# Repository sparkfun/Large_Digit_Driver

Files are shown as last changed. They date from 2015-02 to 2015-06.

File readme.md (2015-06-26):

SparkFun Large Digit Driver
============================
SparkFun Large Digit Driver

[*SparkFun Large Digit Driver (WIG-13279)*](https://www.sparkfun.com/products/13279)

The SparkFun Large Digit Driver is a chainable controller backpack that can be soldered directly to the back of our large 6.5" 7-segment displays.

Repository Contents
-------------------

* **/Firmware** - Example code 
* **/Hardware** - Eagle design files (.brd, .sch)
* **/Production** - Production panel files (.brd)

Documentation
--------------
* **[Hookup Guide](https://learn.sparkfun.com/tutorials/large-digit-driver-hookup-guide)** - Basic hookup guide for the Large Digit Driver.
* **[SparkFun Fritzing repo](https://github.com/sparkfun/Fritzing_Parts)** - Fritzing diagrams for SparkFun products.
* **[SparkFun 3D Model repo](https://github.com/sparkfun/3D_Models)** - 3D models of SparkFun products. 

License Information
-------------------

This product is _**open source**_! 

Please review the LICENSE.md file for license information. 

If you have any questions or concerns on licensing, please contact techsupport@sparkfun.com.

Distributed as-is; no warranty is given.

- Your friends at SparkFun.

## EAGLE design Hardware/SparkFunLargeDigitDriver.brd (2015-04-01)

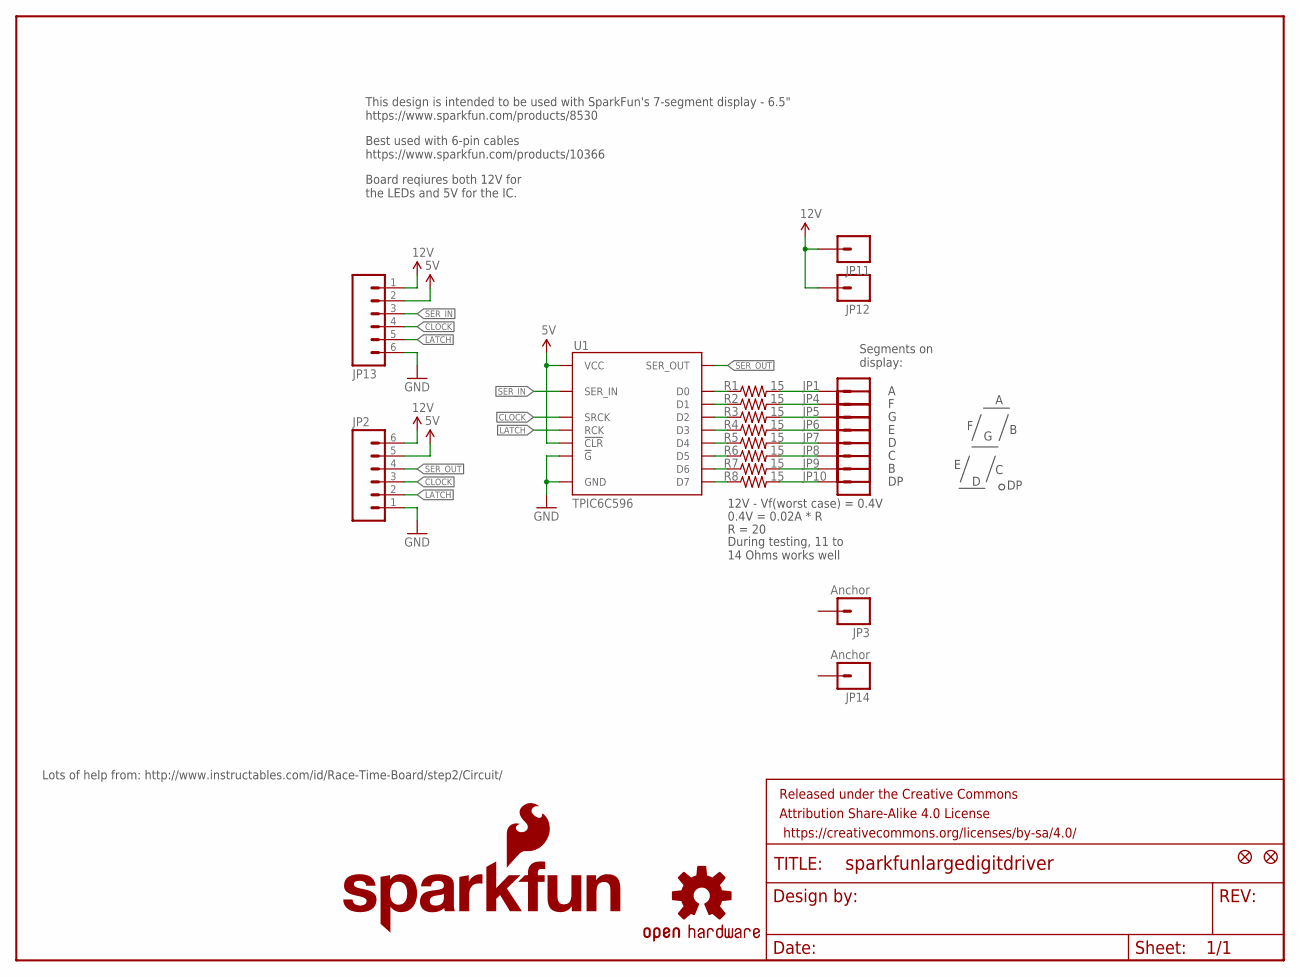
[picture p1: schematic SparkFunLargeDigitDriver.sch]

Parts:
FID1, FID2: FIDUCIAL1X2; FIDUCIAL-1X2
FRAME1: FRAME-LETTER; CREATIVE_COMMONS
JP1, JP4, JP5, JP6, JP7, JP8, JP9, JP10, JP11, JP12: M01PTH_LONGPAD; 1X01_LONGPAD
JP2, JP13: M06SMD; 1X06-SMD
JP3, JP14: Anchor; 1X01_LONGPAD
LOGO1: SFE_LOGO_NAME_FLAME.1_INCH; SFE_LOGO_NAME_FLAME_.1
LOGO2: OSHW-LOGOS; OSHW-LOGO-S
R1, R2, R3, R4, R5, R6, R7, R8: 15; 0603-RES
U1: TPIC6C596; SO016

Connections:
5V: JP2.5, JP13.2, U1.1 (VCC), U1.7 (!CLR)
12V: JP2.6, JP11.1, JP12.1, JP13.1
CLOCK: JP2.3, JP13.4, U1.15 (SRCK)
D0: R1.1, U1.3 (D0)
D1: R2.1, U1.4 (D1)
D2: R3.1, U1.5 (D2)
D3: R4.1, U1.6 (D3)
D4: R5.1, U1.11 (D4)
D5: R6.1, U1.12 (D5)
D6: R7.1, U1.13 (D6)
D7: R8.1, U1.14 (D7)
GND: JP2.1, JP13.6, U1.8 (!G), U1.16 (GND)
LATCH: JP2.2, JP13.5, U1.10 (RCK)
S0: JP1.1, R1.2
S1: JP4.1, R2.2
S2: JP5.1, R3.2
S3: JP6.1, R4.2
S4: JP7.1, R5.2
S5: JP8.1, R6.2
S6: JP9.1, R7.2
S7: JP10.1, R8.2
SER_IN: JP13.3, U1.2 (SER_IN)
SER_OUT: JP2.4, U1.9 (SER_OUT)

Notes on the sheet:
Lots of help from: http://www.instructables.com/id/Race-Time-Board/step2/Circuit/
Segments on display:
12V - Vf(worst case) = 0.4V
0.4V = 0.02A * R
R = 20
This design is intended to be used with SparkFun's 7-segment display - 6.5" https://www.sparkfun.com/products/8530
During testing, 11 to 14 Ohms works well
Best used with 6-pin cables https://www.sparkfun.com/products/10366
Board reqiures both 12V for the LEDs and 5V for the IC.

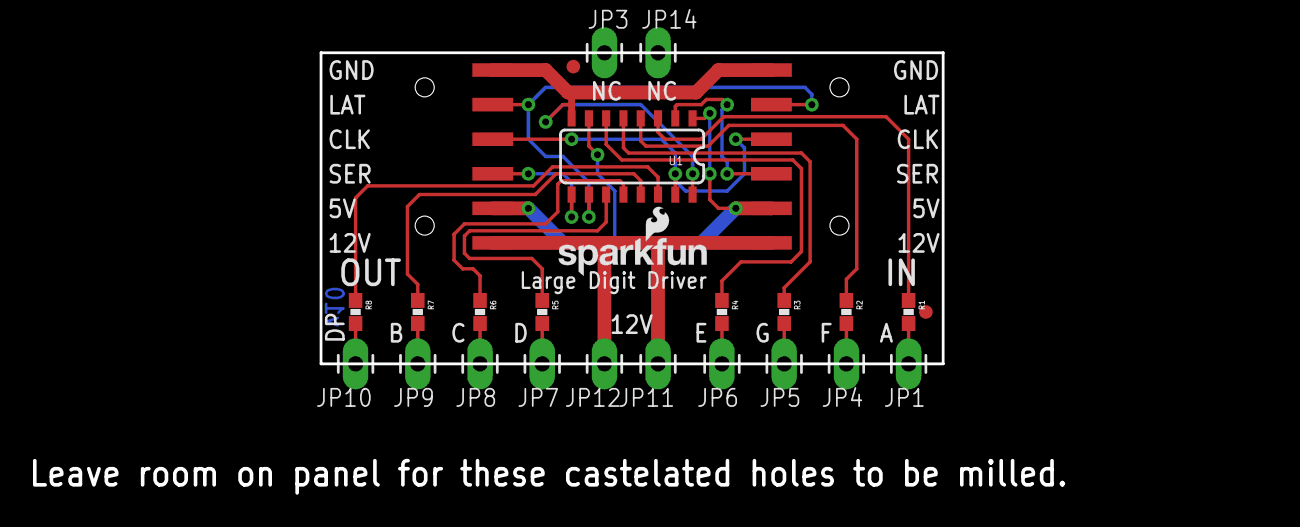
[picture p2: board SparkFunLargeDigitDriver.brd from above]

Board: 2 copper layers, 45.7 x 22.9 mm, 28 parts (1 on the bottom side), 23 nets.

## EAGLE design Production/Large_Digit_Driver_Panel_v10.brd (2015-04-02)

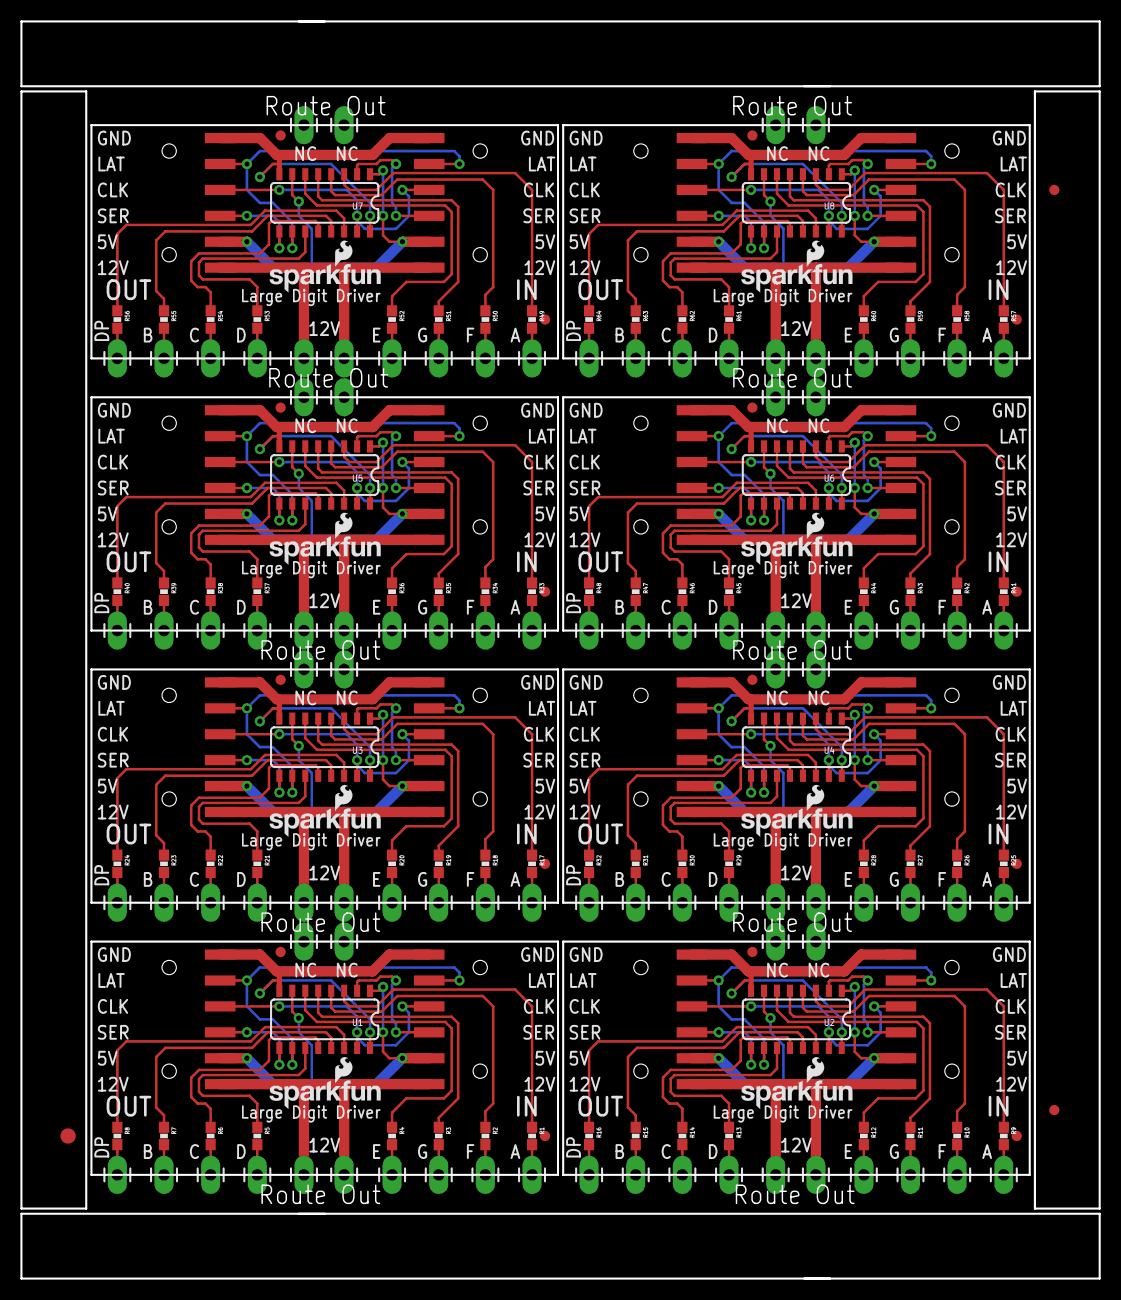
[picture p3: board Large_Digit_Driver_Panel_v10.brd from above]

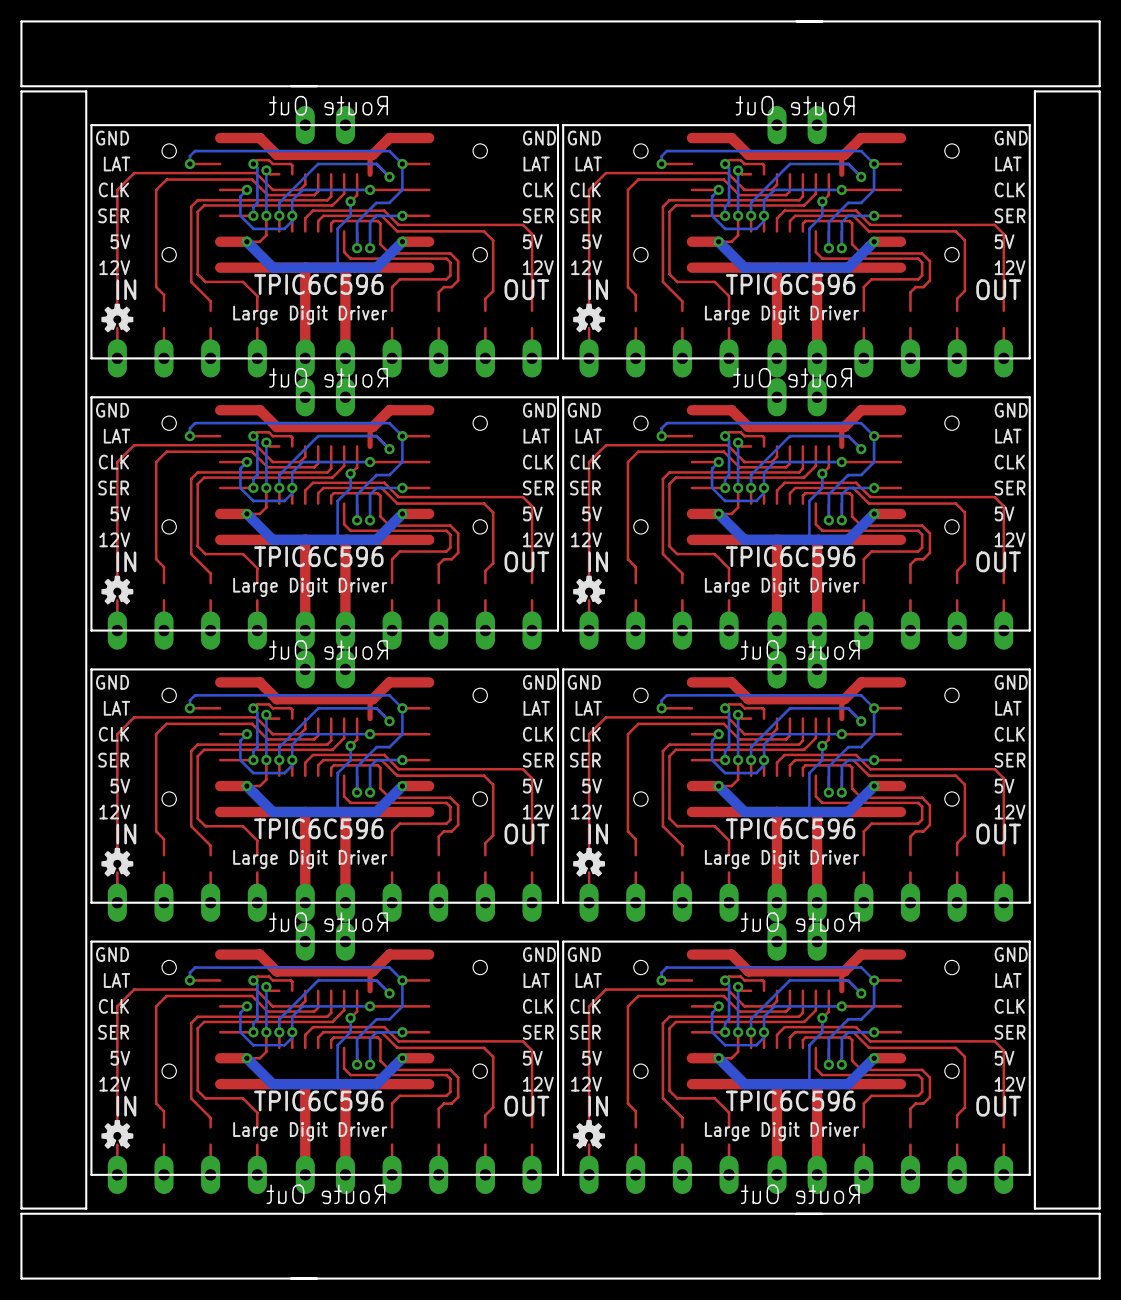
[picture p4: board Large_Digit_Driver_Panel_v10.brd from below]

Board: 2 copper layers, 105.7 x 123.2 mm, 219 parts (8 on the bottom side), 184 nets.

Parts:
E$1: FIDUCIAL-1.5X3
E$4, E$5: FIDUCIAL-1X2
FID1, FID2, FID3, FID4, FID5, FID6, FID7, FID8, FID9, FID10, FID11, FID12, FID13, FID14, FID15, FID16: FIDUCIAL1X2; FIDUCIAL-1X2
JP1, JP4, JP5, JP6, JP7, JP8, JP9, JP10, JP11, JP12, JP16, JP17, JP18, JP19, JP20, JP21, JP22, JP23, JP24, JP25, JP30, JP31, JP32, JP33, JP34, JP35, JP36, JP37, JP38, JP39, JP44, JP45, JP46, JP47, JP48, JP49, JP50, JP51, JP52, JP53, JP58, JP59, JP60, JP61, JP62, JP63, JP64, JP65, JP66, JP67, JP72, JP73, JP74, JP75, JP76, JP77, JP78, JP79, JP80, JP81, JP86, JP87, JP88, JP89, JP90, JP91, JP92, JP93, JP94, JP95, JP100, JP101, JP102, JP103, JP104, JP105, JP106, JP107, JP108, JP109: 1X01_LONGPAD
JP2, JP13, JP15, JP26, JP29, JP40, JP43, JP54, JP57, JP68, JP71, JP82, JP85, JP96, JP99, JP110: 1X06-SMD
JP3, JP14, JP27, JP28, JP41, JP42, JP55, JP56, JP69, JP70, JP83, JP84, JP97, JP98, JP111, JP112: Anchor; 1X01_LONGPAD
LOGO1, LOGO4, LOGO6, LOGO8, LOGO10, LOGO12, LOGO14, LOGO16: SFE_LOGO_NAME_FLAME.1_INCH; SFE_LOGO_NAME_FLAME_.1
LOGO2, LOGO3, LOGO5, LOGO7, LOGO9, LOGO11, LOGO13, LOGO15: OSHW-LOGOS; OSHW-LOGO-S
R1, R2, R3, R4, R5, R6, R7, R8, R9, R10, R11, R12, R13, R14, R15, R16, R17, R18, R19, R20, R21, R22, R23, R24, R25, R26, R27, R28, R29, R30, R31, R32, R33, R34, R35, R36, R37, R38, R39, R40, R41, R42, R43, R44, R45, R46, R47, R48, R49, R50, R51, R52, R53, R54, R55, R56, R57, R58, R59, R60, R61, R62, R63, R64: 15; 0603-RES
U1, U2, U3, U4, U5, U6, U7, U8: TPIC6C596; SO016

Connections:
5V: JP2.5, JP13.2, U1.1, U1.7
5V1: JP15.5, JP26.2, U2.1, U2.7
5V2: JP29.5, JP40.2, U3.1, U3.7
5V3: JP43.5, JP54.2, U4.1, U4.7
5V4: JP57.5, JP68.2, U5.1, U5.7
5V5: JP71.5, JP82.2, U6.1, U6.7
5V6: JP85.5, JP96.2, U7.1, U7.7
5V7: JP99.5, JP110.2, U8.1, U8.7
12V: JP2.6, JP11.1, JP12.1, JP13.1
12V1: JP15.6, JP24.1, JP25.1, JP26.1
12V2: JP29.6, JP38.1, JP39.1, JP40.1
12V3: JP43.6, JP52.1, JP53.1, JP54.1
12V4: JP57.6, JP66.1, JP67.1, JP68.1
12V5: JP71.6, JP80.1, JP81.1, JP82.1
12V6: JP85.6, JP94.1, JP95.1, JP96.1
12V7: JP99.6, JP108.1, JP109.1, JP110.1
CLOCK: JP2.3, JP13.4, U1.15
CLOCK1: JP15.3, JP26.4, U2.15
CLOCK2: JP29.3, JP40.4, U3.15
CLOCK3: JP43.3, JP54.4, U4.15
CLOCK4: JP57.3, JP68.4, U5.15
CLOCK5: JP71.3, JP82.4, U6.15
CLOCK6: JP85.3, JP96.4, U7.15
CLOCK7: JP99.3, JP110.4, U8.15
D0: R1.1, U1.3
D1: R2.1, U1.4
D2: R3.1, U1.5
D3: R4.1, U1.6
D4: R5.1, U1.11
D5: R6.1, U1.12
D6: R7.1, U1.13
D7: R8.1, U1.14
D8: R9.1, U2.3
D9: R10.1, U2.4
D10: R11.1, U2.5
D11: R12.1, U2.6
D12: R13.1, U2.11
D13: R14.1, U2.12
D14: R15.1, U2.13
D15: R16.1, U2.14
D16: R17.1, U3.3
D17: R18.1, U3.4
D18: R19.1, U3.5
D19: R20.1, U3.6
D20: R21.1, U3.11
D21: R22.1, U3.12
D22: R23.1, U3.13
D23: R24.1, U3.14
D24: R25.1, U4.3
D25: R26.1, U4.4
D26: R27.1, U4.5
D27: R28.1, U4.6
D28: R29.1, U4.11
D29: R30.1, U4.12
D30: R31.1, U4.13
D31: R32.1, U4.14
D32: R33.1, U5.3
D33: R34.1, U5.4
D34: R35.1, U5.5
D35: R36.1, U5.6
D36: R37.1, U5.11
D37: R38.1, U5.12
D38: R39.1, U5.13
D39: R40.1, U5.14
D40: R41.1, U6.3
D41: R42.1, U6.4
D42: R43.1, U6.5
D43: R44.1, U6.6
D44: R45.1, U6.11
D45: R46.1, U6.12
D46: R47.1, U6.13
D47: R48.1, U6.14
D48: R49.1, U7.3
D49: R50.1, U7.4
D50: R51.1, U7.5
D51: R52.1, U7.6
D52: R53.1, U7.11
D53: R54.1, U7.12
D54: R55.1, U7.13
D55: R56.1, U7.14
D56: R57.1, U8.3
D57: R58.1, U8.4
D58: R59.1, U8.5
D59: R60.1, U8.6
D60: R61.1, U8.11
D61: R62.1, U8.12
D62: R63.1, U8.13
D63: R64.1, U8.14
GND: JP2.1, JP13.6, U1.8, U1.16
GND1: JP15.1, JP26.6, U2.8, U2.16
GND2: JP29.1, JP40.6, U3.8, U3.16
GND3: JP43.1, JP54.6, U4.8, U4.16
GND4: JP57.1, JP68.6, U5.8, U5.16
GND5: JP71.1, JP82.6, U6.8, U6.16
GND6: JP85.1, JP96.6, U7.8, U7.16
GND7: JP99.1, JP110.6, U8.8, U8.16
LATCH: JP2.2, JP13.5, U1.10
LATCH1: JP15.2, JP26.5, U2.10
LATCH2: JP29.2, JP40.5, U3.10
LATCH3: JP43.2, JP54.5, U4.10
LATCH4: JP57.2, JP68.5, U5.10
LATCH5: JP71.2, JP82.5, U6.10
LATCH6: JP85.2, JP96.5, U7.10
LATCH7: JP99.2, JP110.5, U8.10
S0: JP1.1, R1.2
S1: JP4.1, R2.2
S2: JP5.1, R3.2
S3: JP6.1, R4.2
S4: JP7.1, R5.2
S5: JP8.1, R6.2
S6: JP9.1, R7.2
S7: JP10.1, R8.2
S8: JP16.1, R9.2
S9: JP17.1, R10.2
S10: JP18.1, R11.2
S11: JP19.1, R12.2
S12: JP20.1, R13.2
S13: JP21.1, R14.2
S14: JP22.1, R15.2
S15: JP23.1, R16.2
S16: JP30.1, R17.2
S17: JP31.1, R18.2
S18: JP32.1, R19.2
S19: JP33.1, R20.2
S20: JP34.1, R21.2
S21: JP35.1, R22.2
S22: JP36.1, R23.2
S23: JP37.1, R24.2
S24: JP44.1, R25.2
S25: JP45.1, R26.2
S26: JP46.1, R27.2
S27: JP47.1, R28.2
S28: JP48.1, R29.2
S29: JP49.1, R30.2
S30: JP50.1, R31.2
S31: JP51.1, R32.2
S32: JP58.1, R33.2
S33: JP59.1, R34.2
S34: JP60.1, R35.2
S35: JP61.1, R36.2
S36: JP62.1, R37.2
S37: JP63.1, R38.2
S38: JP64.1, R39.2
S39: JP65.1, R40.2
S40: JP72.1, R41.2
S41: JP73.1, R42.2
S42: JP74.1, R43.2
S43: JP75.1, R44.2
S44: JP76.1, R45.2
S45: JP77.1, R46.2
S46: JP78.1, R47.2
S47: JP79.1, R48.2
S48: JP86.1, R49.2
S49: JP87.1, R50.2
S50: JP88.1, R51.2
S51: JP89.1, R52.2
S52: JP90.1, R53.2
S53: JP91.1, R54.2
S54: JP92.1, R55.2
S55: JP93.1, R56.2
S56: JP100.1, R57.2
S57: JP101.1, R58.2
S58: JP102.1, R59.2
S59: JP103.1, R60.2
S60: JP104.1, R61.2
S61: JP105.1, R62.2
S62: JP106.1, R63.2
S63: JP107.1, R64.2
SER_IN: JP13.3, U1.2
SER_IN1: JP26.3, U2.2
SER_IN2: JP40.3, U3.2
SER_IN3: JP54.3, U4.2
SER_IN4: JP68.3, U5.2
SER_IN5: JP82.3, U6.2
SER_IN6: JP96.3, U7.2
SER_IN7: JP110.3, U8.2
SER_OUT: JP2.4, U1.9
SER_OUT1: JP15.4, U2.9
SER_OUT2: JP29.4, U3.9
SER_OUT3: JP43.4, U4.9
SER_OUT4: JP57.4, U5.9
SER_OUT5: JP71.4, U6.9
SER_OUT6: JP85.4, U7.9
SER_OUT7: JP99.4, U8.9

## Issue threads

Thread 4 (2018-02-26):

Display showing 88 (All leds are glowing)

afsar95, 2018-02-26:
We have developed a prototype using Large_digits with nodemcu, Everything is fine when connections made out of jumper wires but digit shows 88 when the connections made in PCB...I used 12v to 5v voltage(1amps)  regulator for powering board please help with me..Thanks in advance...

nseidle, 2018-02-26:
Perhaps you could post your code, or a schematic? Otherwise, I have really no idea.

afsar95, 2018-02-27:
#include <DHT.h>
#define DHTPIN 2    //d4
#define DHTTYPE DHT22
#define HUM_LED 14       //D5                
#define TEM_LED 12       //D6

DHT dht(DHTPIN, DHTTYPE);

byte segmentClock = 5;//D1
byte segmentLatch = 4;//D2
byte segmentData = 0;//D3
//esp8266 nodemcu
void setup() {
  Serial.begin(115200);
  pinMode(segmentClock, OUTPUT);
  pinMode(segmentData, OUTPUT);
  pinMode(segmentLatch, OUTPUT);
  pinMode(HUM_LED, OUTPUT);
  pinMode(TEM_LED, OUTPUT);
  digitalWrite(HUM_LED, LOW);
  digitalWrite(TEM_LED, LOW);
  digitalWrite(segmentClock, LOW);
  digitalWrite(segmentData, LOW);
  digitalWrite(segmentLatch, LOW);
  dht.begin();
  showNumber1(88);
  digitalWrite(HUM_LED, HIGH);
  digitalWrite(TEM_LED, HIGH);
  delay(3000);
}

void loop() {
  int Humidity = dht.readHumidity();
  Humidity = Humidity - 3;   //ADJUSTMENT
  int Temperature_Cel = dht.readTemperature();
  if (isnan(Humidity) || isnan(Temperature_Cel))
  {
    Serial.println("Failed to read from DHT sensor!");
  }
  if ((Humidity > 0 && Temperature_Cel > 0) && (Humidity < 100 && Temperature_Cel < 100)) {
    Serial.print("Humidity: ");
    Serial.print(Humidity);
    Serial.print(" %\t");
    Serial.print("Temperature: ");
    Serial.print(Temperature_Cel);
    Serial.print(" *C ");
    digitalWrite(HUM_LED, HIGH);
    digitalWrite(TEM_LED, LOW);
    showNumber(Humidity);
    delay(2000);
    digitalWrite(HUM_LED, LOW);
    digitalWrite(TEM_LED, HIGH);
    showNumber(Temperature_Cel);
    delay(2000);
  }
  else {
    Serial.println("invalid data");
  }

}
void showNumber(float value)
{
  int number = abs(value); //Remove negative signs and any decimals
  for (byte x = 0 ; x < 2 ; x++)
  {
    int remainder = number % 10;
    postNumber(remainder, false);
    number /= 10;
  }
  digitalWrite(segmentLatch, LOW);
  digitalWrite(segmentLatch, HIGH);
}
void postNumber(byte number, boolean decimal)
{
#define a  1<<0
#define b  1<<6
#define c  1<<5
#define d  1<<4
#define e  1<<3
#define f  1<<1
#define g  1<<2
#define dp 1<<7
  byte segments;
  switch (number)
  {
    case 1: segments = b | c; break;
    case 2: segments = a | b | d | e | g; break;
    case 3: segments = a | b | c | d | g; break;
    case 4: segments = f | g | b | c; break;
    case 5: segments = a | f | g | c | d; break;
    case 6: segments = a | f | g | e | c | d; break;
    case 7: segments = a | b | c; break;
    case 8: segments = a | b | c | d | e | f | g; break;
    case 9: segments = a | b | c | d | f | g; break;
    case 0: segments = a | b | c | d | e | f; break;
    case ' ': segments = 0; break;
    case 'c': segments = g | e | d; break;
    case '-': segments = g; break;
    case 't': segments = g | e | d | f; break;
    case 'u': segments = b | c | d | e | f; break;
    case 'l': segments = d | e | f; break;
    case 'h': segments = f | e | g | c; break;
    case 's': segments = a | f | g | c | d; break;
  }
  if (decimal) segments |= dp;
  for (byte x = 0 ; x < 8 ; x++)
  {
    digitalWrite(segmentClock, LOW);
    digitalWrite(segmentData, segments & 1 << (7 - x));
    digitalWrite(segmentClock, HIGH);
  }
}
void showNumber1(float value)
{
  int number = abs(value);
  for (byte x = 0 ; x < 2 ; x++)
  {
    int remainder = number % 10;
    postNumber(remainder, true);
    number /= 10;
  }
  digitalWrite(segmentLatch, LOW);
  digitalWrite(segmentLatch, HIGH);
}

nseidle, 2018-02-27:
Hi - I recommend you work on the thing that does not work: the display. To do this, remove the code for your humidity and temp sensing until you get the display working. Then add code back slowly.

It looks like you are using our example code which is a very good place to start. I'm not sure why NodeMCU doesn't work. Perhaps because it is 3.3V and the backpack is expecting 5V.

afsar95, 2018-02-27:
Thank you @nseidle
We are using 2A power supply so can you tell me what's the appropriate current rating for two digit display along with nodemcu.

nseidle, 2018-02-27:
Please read the [display datasheet](https://www.sparkfun.com/datasheets/Components/YSD-1600AR6F-89.pdf) and the [backpack schematic](https://cdn.sparkfun.com/datasheets/Widgets/Large%20Digit%20Driver.pdf). Each segment has a 15Ohm resistor in line to limit the segment current to 20mA per segment. If all 7 segments are on, this is 20*7 = 140mA per digit.

A 12V 2A supply should be more than enough!

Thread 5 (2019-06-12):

Turning Off Segments

yawuar, 2019-06-12:
Hi

So I made a little project with 4 - 7 segment Display 4" (For every display I had to use the sparkfun large digit driver ofc!) and I've use a gyroscope to hold track of the rotation, every time when it has rotated for 360 degrees it increments the counter and it shows on the display.

This project is running on a battery of 50.000mAh, a.t.m I'm trying to reduce battery (project needs to run at least a week without changing battery). So I was thinking to turn off the displays when the gyro is not rotating. I programmed it, working well but there is 1 problem. Every time I clear the segments (when the gyro is not rotating) one of my sparkfun large digit driver IC gets very **warm**. I've use the showNumber function to check if the IC still gets hot but that doesn't happen. This problem is only happening when I clear the segments >.>

This the code That I've been using:

My clearSegments function
```
void clearSegments() {
  for (byte x = 0 ; x < 4 ; x++) {
      postNumber(" ", false);
  }
  digitalWrite(segmentLatch, LOW);
  digitalWrite(segmentLatch, HIGH);
}
```

The postnumber function

```
void postNumber(byte number, boolean decimal)
{
#define a  1<<0
#define b  1<<6
#define c  1<<5
#define d  1<<4
#define e  1<<3
#define f  1<<1
#define g  1<<2
#define dp 1<<7

  byte segments;

  switch (number)
  {
    case 1: segments = g | d; break;
    case 2: segments = f | g | b | dp | c; break;
    case 3: segments = f | g | b | d | c; break;
    case 4: segments = a | b | g | d; break;
    case 5: segments = f | a | b | d | c; break;
    case 6: segments = f | a | b | d | c | dp; break;
    case 7: segments = f | g | d; break;
    case 8: segments = a | b | c | d | dp | f | g; break;
    case 9: segments = a | b | c | d | f | g; break; // a | b | c | d | f | g; break
    case 0: segments = a | g | c | d | dp | f; break;
    case ' ': segments = e; break;
  }

  // Segments not working on 0
  if (decimal) segments |= e;

  //Clock these bits out to the drivers
  for (byte x = 0 ; x < 8 ; x++)
  {
    digitalWrite(segmentClock, LOW);
    digitalWrite(segmentData, segments & 1 << (7 - x));
    digitalWrite(segmentClock, HIGH); //Data transfers to the register on the rising edge of SRCK
  }
}
```

I hope you guys have an idea what I'm doing wrong and how to solve this.
Thank you very much!

nseidle, 2019-06-12:
What type of battery? 50Ahr is a big battery.

My guess is that when you power down the display the voltage on the battery rises above the rated voltage on the driver IC.

Be sure to read the [datasheet](https://cdn.sparkfun.com/datasheets/Widgets/TPIC6C596.pdf) for the max specs. 7V on the logic (really stick to 5V).

I can't see how software would cause the ICs to overheat. It is most likely a wiring or voltage issue.

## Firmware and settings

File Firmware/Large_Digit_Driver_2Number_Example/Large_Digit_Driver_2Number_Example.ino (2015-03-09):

/*
 Controlling large 7-segment displays
 By: Nathan Seidle
 SparkFun Electronics
 Date: February 25th, 2015
 License: This code is public domain but you buy me a beer if you use this and we meet someday (Beerware license).

 This code demonstrates how to post two numbers to a 2-digit display usings two large digit driver boards.

 Here's how to hook up the Arduino pins to the Large Digit Driver IN
 
 Arduino pin 6 -> CLK (Green on the 6-pin cable)
 5 -> LAT (Blue)
 7 -> SER on the IN side (Yellow)
 5V -> 5V (Orange)
 Power Arduino with 12V and connect to Vin -> 12V (Red)
 GND -> GND (Black)

 There are two connectors on the Large Digit Driver. 'IN' is the input side that should be connected to
 your microcontroller (the Arduino). 'OUT' is the output side that should be connected to the 'IN' of addtional
 digits.
 
 Each display will use about 150mA with all segments and decimal point on.
 
*/

//GPIO declarations
//-=-=-=-=-=-=-=-=-=-=-=-=-=-=-=-=-=-=-=-=-=-=-=-=
byte segmentClock = 6;
byte segmentLatch = 5;
byte segmentData = 7;

//-=-=-=-=-=-=-=-=-=-=-=-=-=-=-=-=-=-=-=-=-=-=-=-=

void setup()
{
  Serial.begin(9600);
  Serial.println("Large Digit Driver Example");

  pinMode(segmentClock, OUTPUT);
  pinMode(segmentData, OUTPUT);
  pinMode(segmentLatch, OUTPUT);

  digitalWrite(segmentClock, LOW);
  digitalWrite(segmentData, LOW);
  digitalWrite(segmentLatch, LOW);
}

int number = 0;

void loop()
{
  showNumber(number); //Test pattern
  number++;
  number %= 100; //Reset x after 99
  
  Serial.println(number); //For debugging
  
  delay(500);
}

//Takes a number and displays 2 numbers. Displays absolute value (no negatives)
void showNumber(float value)
{
  int number = abs(value); //Remove negative signs and any decimals

  //Serial.print("number: ");
  //Serial.println(number);

  for (byte x = 0 ; x < 2 ; x++)
  {
    int remainder = number % 10;

    postNumber(remainder, false);

    number /= 10;
  }

  //Latch the current segment data
  digitalWrite(segmentLatch, LOW);
  digitalWrite(segmentLatch, HIGH); //Register moves storage register on the rising edge of RCK
}

//Given a number, or '-', shifts it out to the display
void postNumber(byte number, boolean decimal)
{
  //    -  A
  //   / / F/B
  //    -  G
  //   / / E/C
  //    -. D/DP

#define a  1<<0
#define b  1<<6
#define c  1<<5
#define d  1<<4
#define e  1<<3
#define f  1<<1
#define g  1<<2
#define dp 1<<7

  byte segments;

  switch (number)
  {
    case 1: segments = b | c; break;
    case 2: segments = a | b | d | e | g; break;
    case 3: segments = a | b | c | d | g; break;
    case 4: segments = f | g | b | c; break;
    case 5: segments = a | f | g | c | d; break;
    case 6: segments = a | f | g | e | c | d; break;
    case 7: segments = a | b | c; break;
    case 8: segments = a | b | c | d | e | f | g; break;
    case 9: segments = a | b | c | d | f | g; break;
    case 0: segments = a | b | c | d | e | f; break;
    case ' ': segments = 0; break;
    case 'c': segments = g | e | d; break;
    case '-': segments = g; break;
  }

  if (decimal) segments |= dp;

  //Clock these bits out to the drivers
  for (byte x = 0 ; x < 8 ; x++)
  {
    digitalWrite(segmentClock, LOW);
    digitalWrite(segmentData, segments & 1 << (7 - x));
    digitalWrite(segmentClock, HIGH); //Data transfers to the register on the rising edge of SRCK
  }
}

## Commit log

2015-01-26 Initial Commit.
    [Large Digit Driver.brd, Large Digit Driver.sch]
2015-01-28 Conversion to SMD parts.
    Board is much smaller. Uses TPIC6C596.
    [Large Digit Driver.brd, Large Digit Driver.sch]
2015-01-28 Removed extraneous layers.
    [Large Digit Driver.brd]
2015-01-30 Adding anchor pins for SMD mounting.
    [Large Digit Driver.brd, Large Digit Driver.sch]
2015-02-04 Added fiducials for issue #1.
    [Large Digit Driver.brd, Large Digit Driver.sch]
2015-02-05 moved fiducial from under header
    [Large Digit Driver.brd]
2015-02-05 moved it again, better this time
    [Large Digit Driver.brd]
2015-02-06 Note added to schematic: issue #2
    [Large Digit Driver.sch]
2015-03-09 Changing to 15 Ohm limiting resistors. Adding example code.
    20 Ohm resistors brought current down to 11mA in testing. Decreasing
    resistor size to get higher current per segment.
    [Large Digit Driver.brd, Large Digit Driver.sch]
2015-03-12 Fiducial bump. Adding silk on bottom.
    Fixes issue #3.
    [Large Digit Driver.brd]
2015-03-18 Added silk to anchors. Added power notes to schematic.
    [Large Digit Driver.brd, Large Digit Driver.sch]
2015-03-23 created panel v10
    [Large_Digit_Driver_Panel_v10.brd]
2015-04-01 Fixing logos for easier CAM
    [Large Digit Driver.brd, Large Digit Driver.sch]
2015-04-02 fixed logos on panel for better cam
    [Large_Digit_Driver_Panel_v10.brd]
2015-06-26 Adding license file, updating README, fixing directory name, fixing file names
    [Large_Digit_Driver_Panel_v10.brd, SparkFunLargeDigitDriver.brd, SparkFunLargeDigitDriver.sch]

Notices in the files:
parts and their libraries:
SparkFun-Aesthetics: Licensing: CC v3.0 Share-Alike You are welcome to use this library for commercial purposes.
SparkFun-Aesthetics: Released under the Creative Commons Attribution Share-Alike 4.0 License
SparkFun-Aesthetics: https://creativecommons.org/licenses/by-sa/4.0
